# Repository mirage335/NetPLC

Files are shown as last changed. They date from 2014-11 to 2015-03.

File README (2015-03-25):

Copyright (C) 2014 mirage335
See the end of the file for license conditions.
See license.txt for NetPLC license conditions.

Advanced multi-peripherial low-power Networked Programmable Logic Controller (NetPLC) core platform.

__Usage__
NetPLC is intended as a robust control system with networking support. Expected use cases include door locks, occupancy sensors, temperature sensors, efficiency smart meters, thermostats, wind farms, 3D printers, etc.

'General Purpose' and 'Precision Analog' RJ45 jacks may be used to attach attach additional microcontrollers, cameras, thermistors, pressure sensors, current/voltage transformers, power transistors, relays, etc.

In harsh environments (eg. mains voltage, flourescent lighting), surge suppression may be maximized by use of genuine S/FTP cable as well as maintaining AVR pins in output LOW state when possible. Watchdog is also recommended.

Ethernet jack is provided for full 10BaseT support. WiFi support is also provided via RN171 module. Headers are provided for preassembled pin-compatible Ethernet and WiFi peripherials.

For maximum network reliability, consider configuring both Ethernet and WiFi for automatic connection, as mutual fallbacks.

__Design__
Efforts have been made to provide surge suppression, especially for the RJ45 peripherials. However, sustained faults below the spark-gap voltage threshold and above the AVR protection diode current limits will cause damage. As noted above, extra precautions should be taken against such mid-level interference in harsh environments.

Layout is important. Digital circuits create a multitude of full-swing square waves at radio frequency. Stray coupling of these transients into analog circuits can introduce both low and high frequency noise through a variety of mechanisms.

USA companies provide all parts in these schematics.

__Extras__
Any isolated USB charger can be used as a power source. For example, consider http://www.amazon.com/Samsung-Power-Adapter-Detachable-Micro/dp/B0089VO7FQ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 .

Typical 1/16" PCBs will not be thick enough to ensure reliable USB port contact. Consider adding a few layers of electrical or duct tape to the back side.

__Safety__
Typical TCP/IP and wireless networks are vastly more complex, less reliable, more difficult to surge-protect, and less secure than the onboard MCU. Firmware should be written not to depend on network connectivity for control loops where reliability counts. Unrestricted public internet services (eg. HTTP) should be directed through a full server, supporting load and security requirements if possible.

While the MCU alone is unlikely to fail within decades, it should not be relied upon for safety-of-life control systems. Generally, a microcontroller is less dependable than redundant, specialized, discrete logic. Indirect use of NetPLC (eg. monitoring outcomes, contributing information, etc) in such systems must be carefully considered by a competent engineer.

_FutureWork_
*) SD Card slot should be added to enhance database and logging capacity.
*) RN171 should be moved to software serial port, completely freeing the hardware UART for external peripherials.
*) Modbus and DNP3 support have been suggested by George Walker. Related open-source libraries seem to already exist, and may be worth testing.

__Copyright__
This file is part of NetPLC.

NetPLC is free software: you can redistribute it and/or modify
it under the terms of the GNU General Public License as published by
the Free Software Foundation, either version 3 of the License, or
(at your option) any later version.

NetPLC is distributed in the hope that it will be useful,
but WITHOUT ANY WARRANTY; without even the implied warranty of
MERCHANTABILITY or FITNESS FOR A PARTICULAR PURPOSE.  See the
GNU General Public License for more details.

You should have received a copy of the GNU General Public License
along with NetPLC.  If not, see <http://www.gnu.org/licenses/>.

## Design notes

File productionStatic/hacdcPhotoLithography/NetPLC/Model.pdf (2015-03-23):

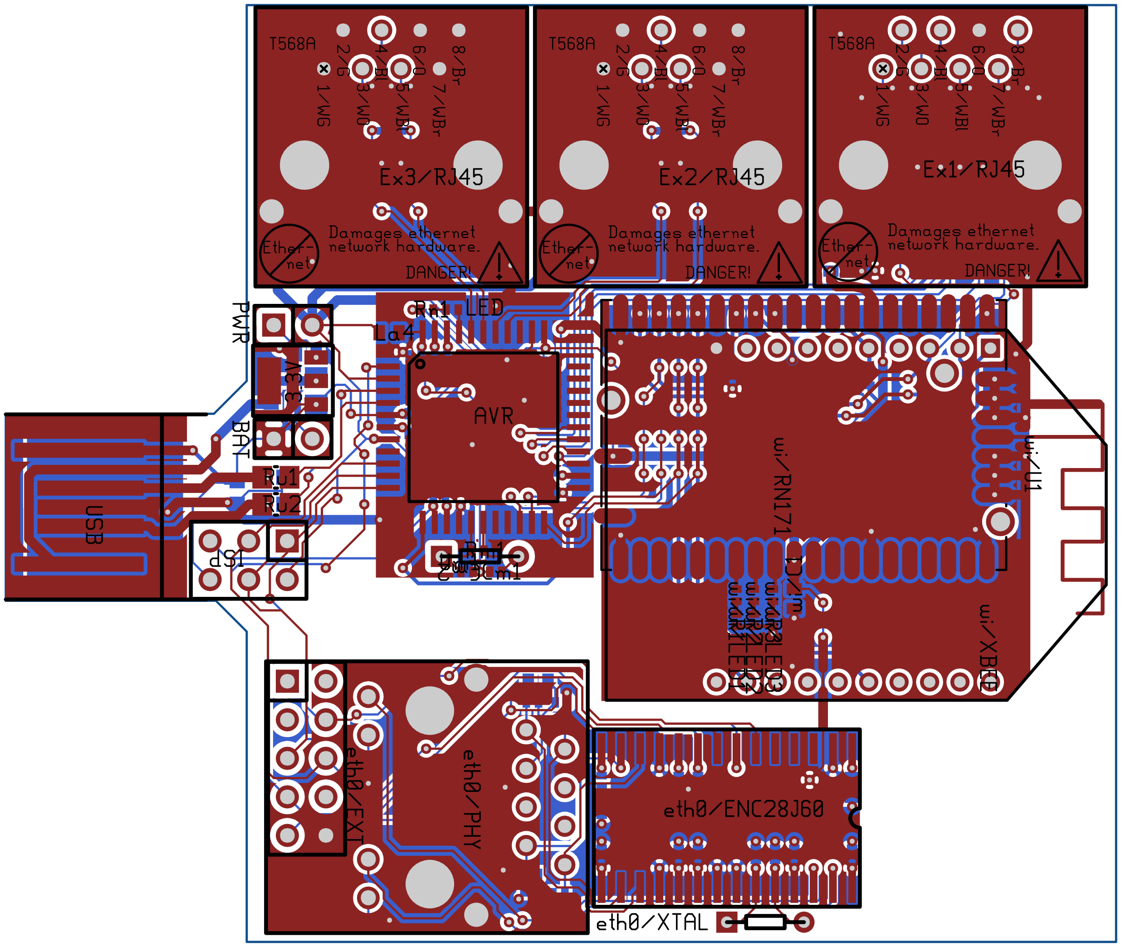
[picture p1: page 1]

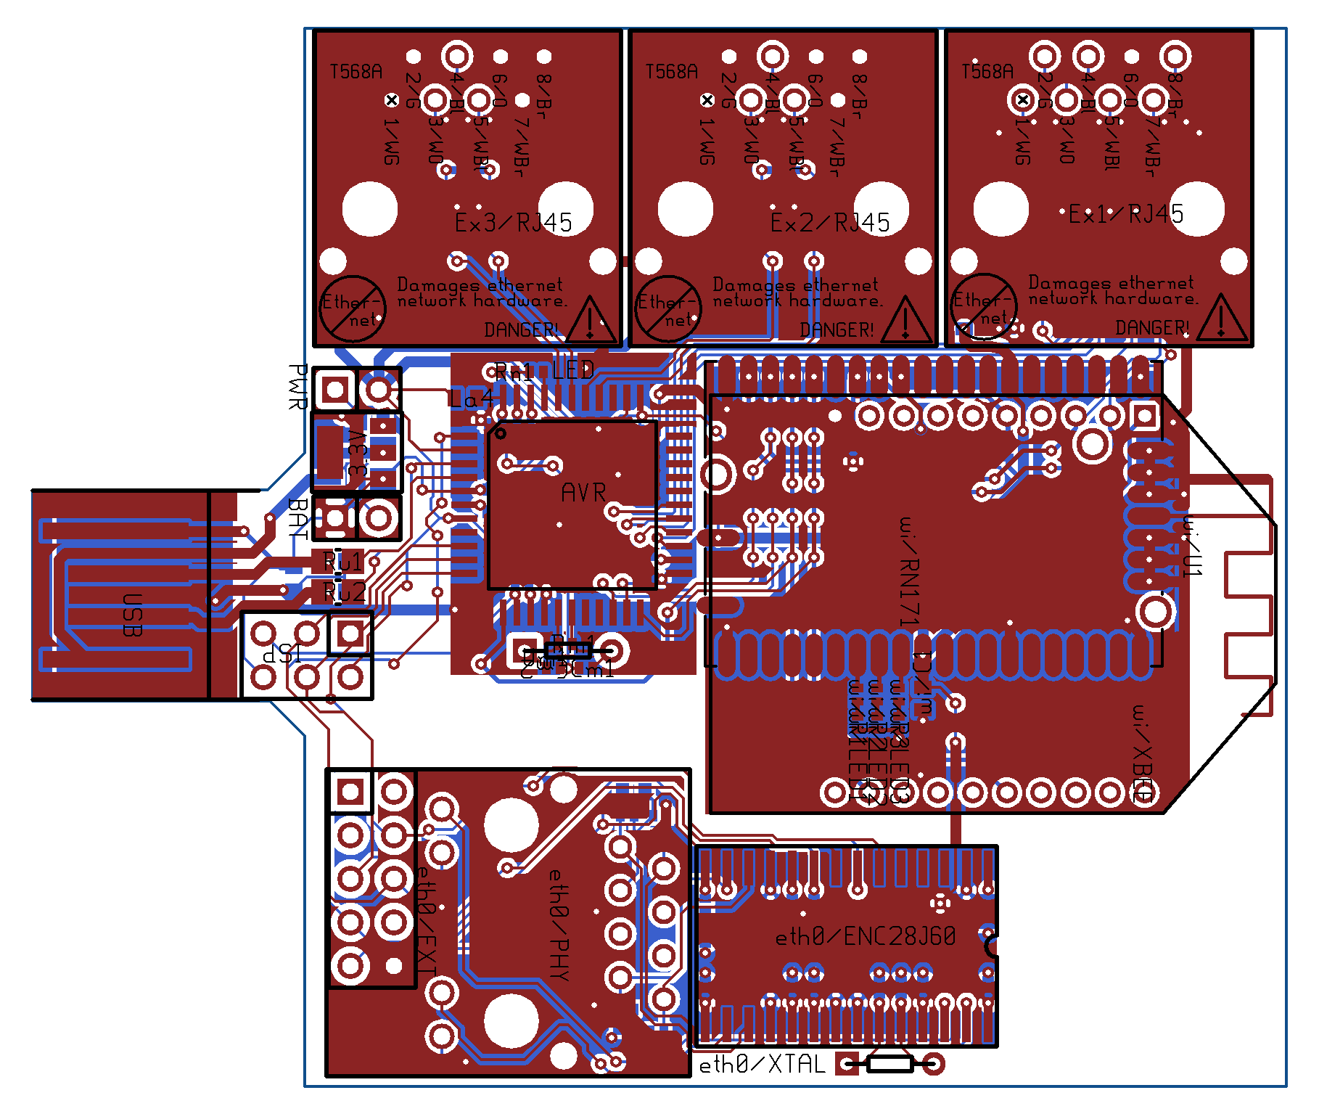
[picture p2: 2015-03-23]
productionStatic/cad/NetPLC/Render.png

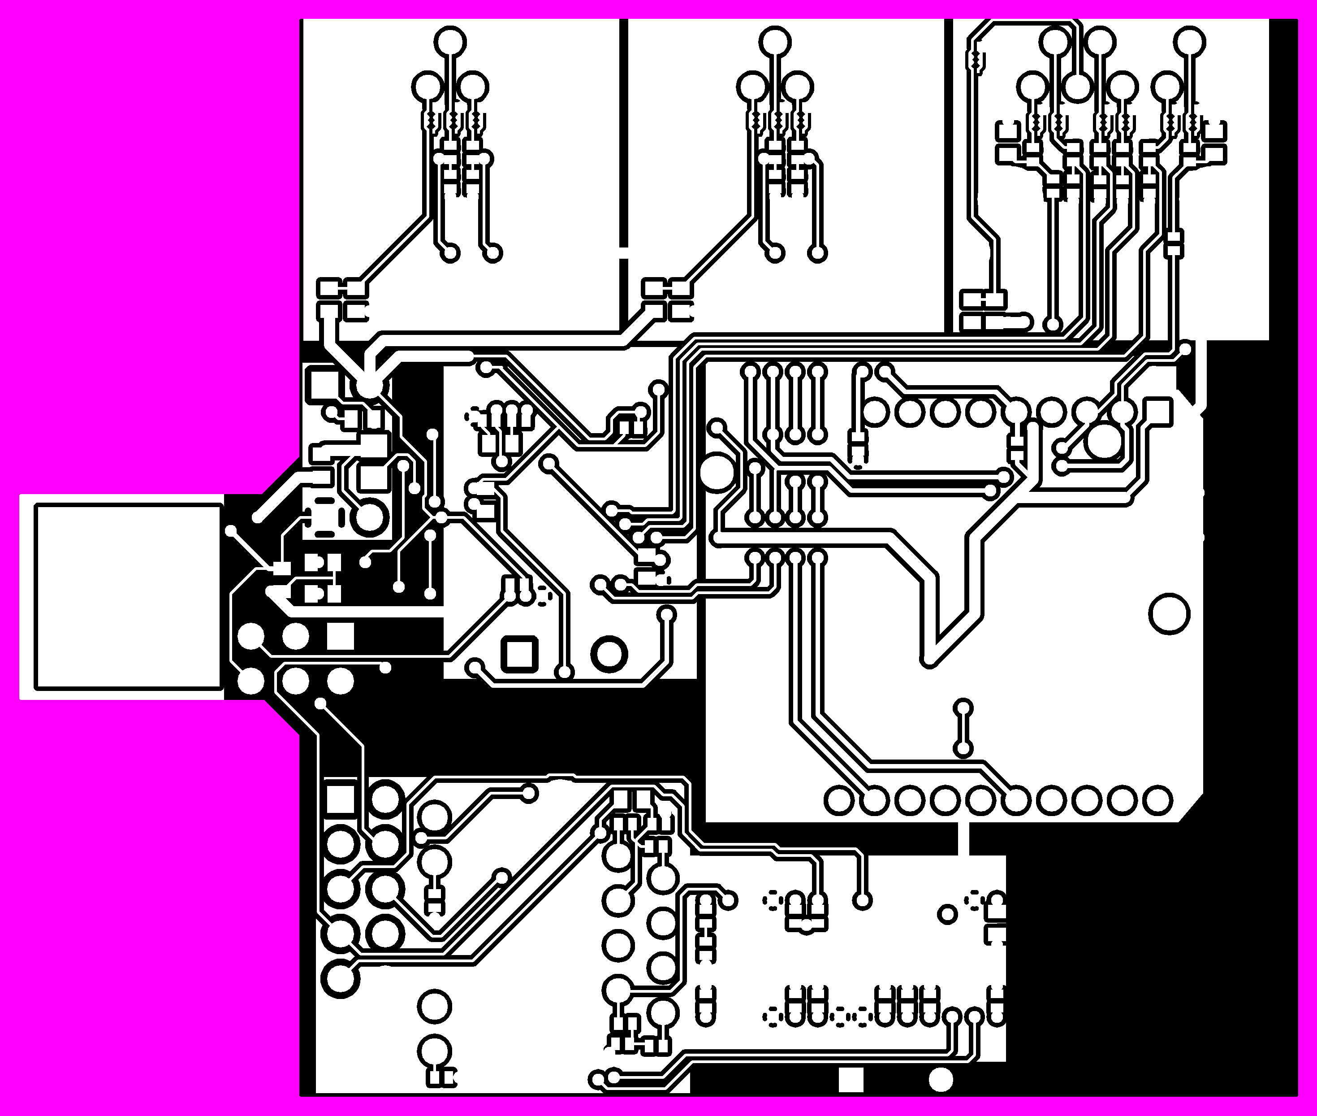
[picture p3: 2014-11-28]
productionStatic/hacdcCNC/NetPLC/outp4_masked.png

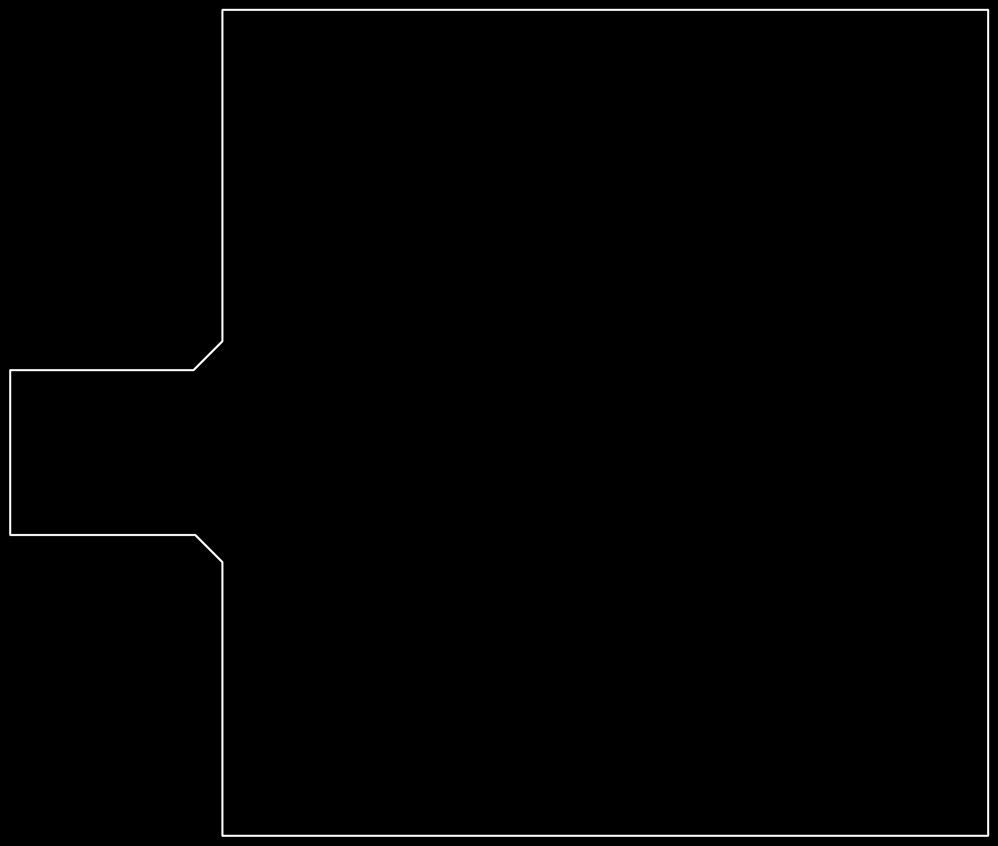
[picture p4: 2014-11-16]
productionStatic/hacdcCNC/NetPLC/outp2_original_outline.png

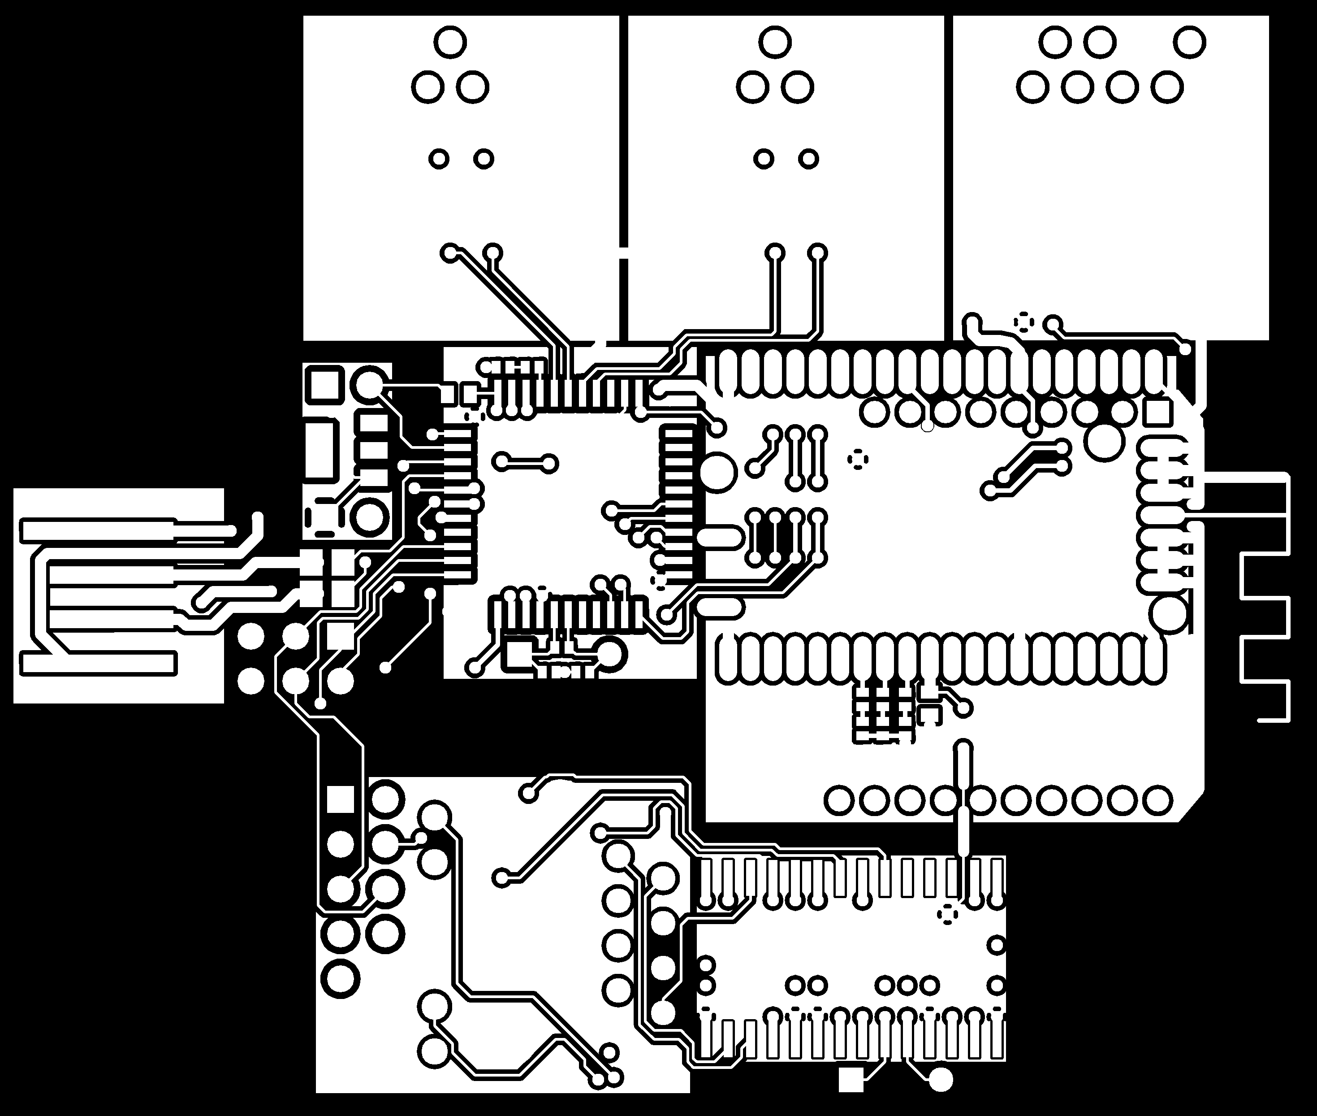
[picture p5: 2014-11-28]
productionStatic/hacdcCNC/NetPLC/outp1_original_front.png

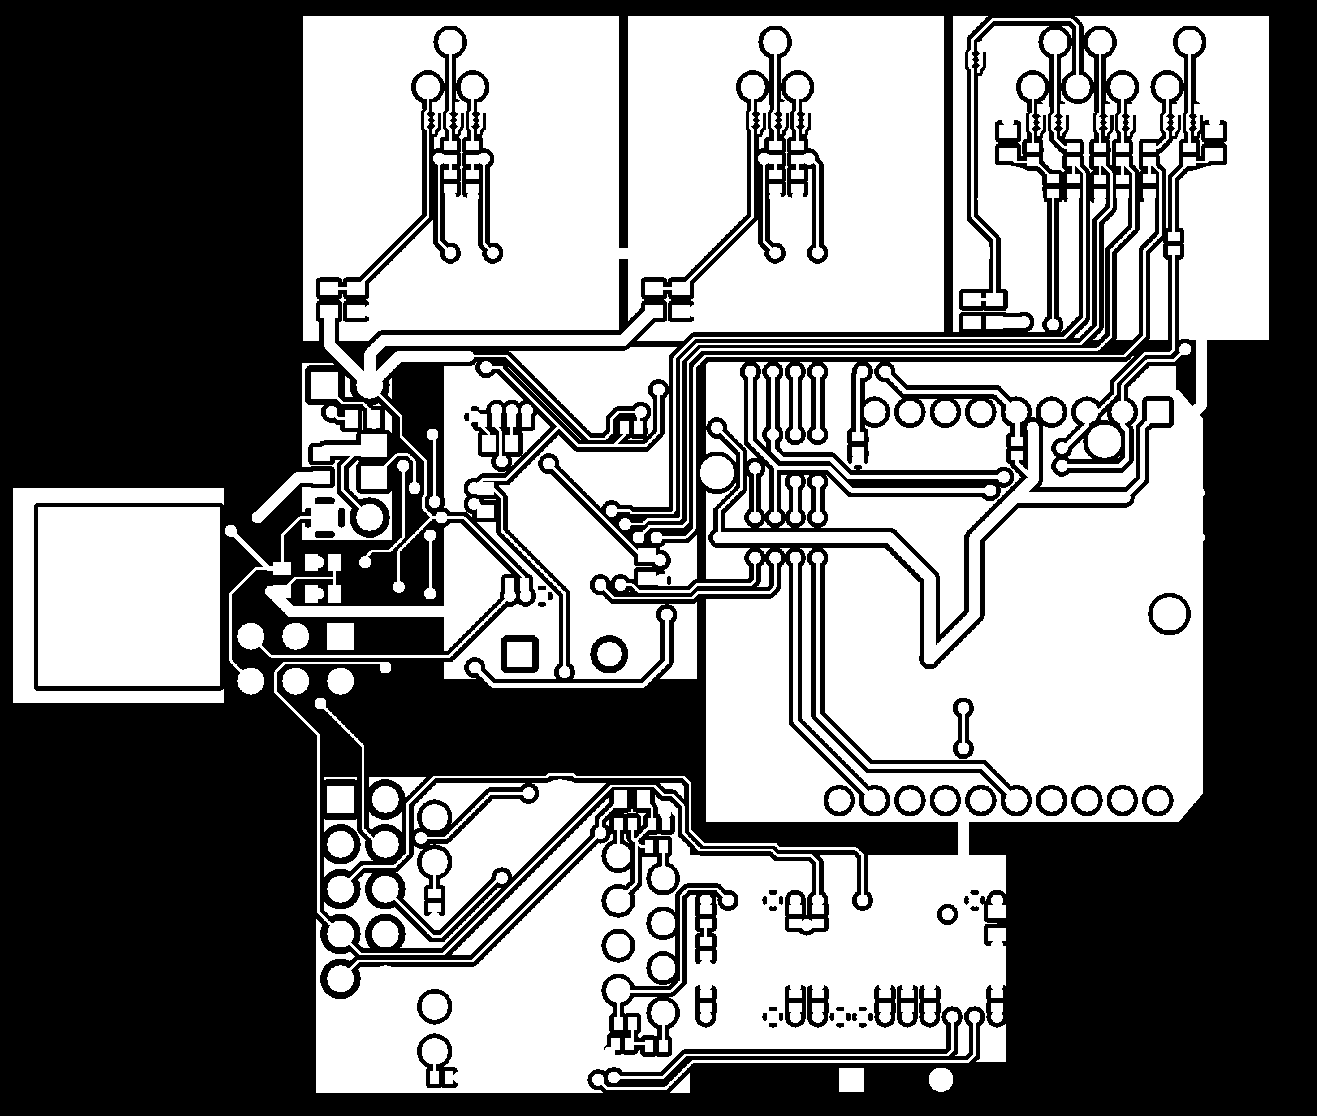
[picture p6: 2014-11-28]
productionStatic/hacdcCNC/NetPLC/outp0_original_back.png

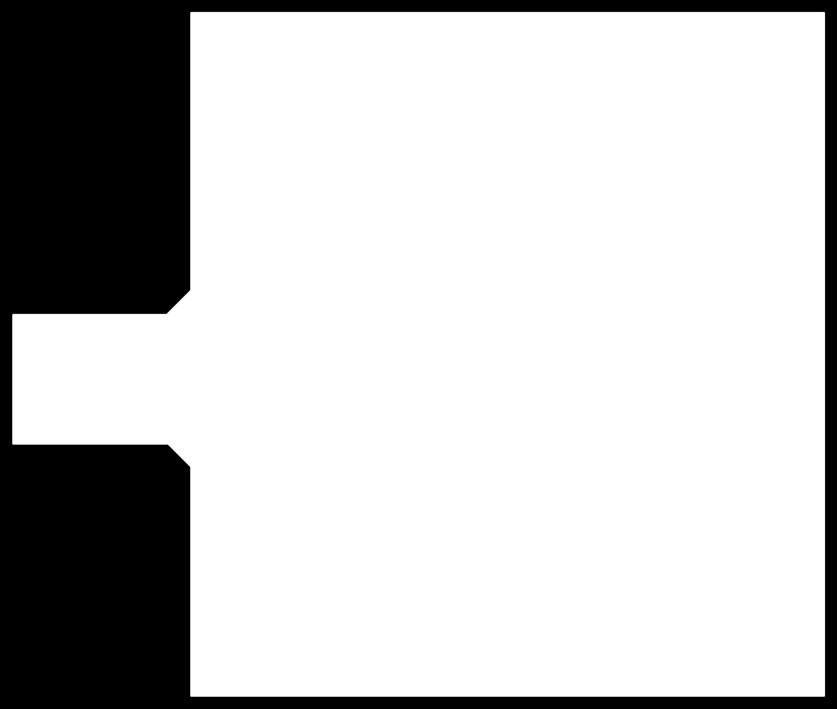
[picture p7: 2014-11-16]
productionStatic/hacdcCNC/NetPLC/outp3_outline_filled.png

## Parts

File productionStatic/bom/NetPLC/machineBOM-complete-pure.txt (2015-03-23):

AVR:ATMEGA32U4-AU:-:TQFP44_10:$6.04 MOUSER 556-ATMEGA32U4-AU:1
Rm1:RESISTOR:1M:0402:$0.14 MOUSER 594-MCS04020C1004FE0:1
Um1:CRYSTAL:16MHz:ACY200:$0.39 MOUSER ABL-16.000MHZ-B2:1
Ru1,Ru2:RESISTOR:22:0805:$0.52 MOUSER 71-TNPW080522R1BEEA:2
USB:CONNECTOR_5:-:USB_TypeA_PCB:$0.00 PCB-INTEGRAL Trace based connector.:1
3.3V:Microchip MCP170x regulator TO92:-:SOT89:$0.60 MOUSER 579-MCP1703AT3302EMB:1
ISP:CONNECTOR_6:-:HEADER6_2:$0.25 MOUSER 649-77313-818-06LF:1
BAT,PWR:CONNECTOR_2:-:HEADER2_1:-:2
eth0/ENC28J60:ENC28J60:-:SO28:$3.40 MOUSER 579-ENC28J60-I/SO:1
eth0/PHY:CONNECTOR_12:-:MAGJACK:$1.95 SparkFun PRT-08534:1
eth0/EXT:CONNECTOR_10:-:HEADER10_1:-:1
eth0/XTAL:CRYSTAL:25MHz:ACY200:$0.39 MOUSER 815-ABL-25-B2F:1
Cm1,Cm2,eth0/Ce4,eth0/Ce5:CAPACITOR:22p:0402:$0.10 MOUSER 80-C0402C220J5G:4
Ri1,eth0/Re2:RESISTOR:10k:0402:$0.13 MOUSER 71-TNPW040210K0DETD:2
Ex1/MOV1,Ex1/MOV2,Uu1,Uu2:ESD_Suppressor:-:0603:$0.13 MOUSER 652-CG0603MLC-05E:4
Ex1/L1,Ex2/L1,Ex3/L1,La1,La3,La4,Lp1,eth0/Lp1:INDUCTOR:4.7uH:0603:$0.12 MOUSER 70-ILSB0603ER4R7K:8
Ex1/R2,Ex1/R3,Ex1/R4,Ex1/R5,Ex1/R7,Ex1/R8,Ex2/R1,Ex2/R2,Ex3/R1,Ex3/R2,eth0/Rp1,eth0/Rp2,eth0/Rp3,eth0/Rp4:RESISTOR:50:0402:$0.08 MOUSER 71-CRCW0402-49.9-E3:14
Ca2,Ca3,Cm3,Ex1/C2,Ex1/C3,Ex1/C4,Ex1/C5,Ex2/C1,Ex2/C2,Ex3/C1,Ex3/C2,eth0/Ce2,eth0/Ce3,eth0/Ce6,eth0/Ce7,eth0/Ce8,eth0/Cp1,eth0/Cp2:CAPACITOR:0.1u:0402:$0.10 MOUSER 80-C0402C104K8R:18
Ex1/RJ45,Ex2/RJ45,Ex3/RJ45:CONNECTOR_9:-:538-95540-2881:$1.75 MOUSER 538-95540-2881:3
Ex1/SPRK1,Ex1/SPRK2,Ex1/SPRK3,Ex1/SPRK4,Ex1/SPRK5,Ex1/SPRK6,Ex1/SPRK7,Ex2/SPRK1,Ex2/SPRK2,Ex2/SPRK3,Ex3/SPRK1,Ex3/SPRK2,Ex3/SPRK3:GLOW_LAMP:~2kV:SparkGap:-:13
wi/RN171:RN171:12dBm:RN171:$31.50 MOUSER 765-RN-171:1
wi/U1:traceAnt:50Ohm@2.4GHz:50Ohm2point4GHzTraceAntenna:-:1
Ca4,Cp2,Cu1,Ex1/C1,Ex2/C3,Ex3/C3,eth0/Ce1,wi/C1:CAPACITOR:4.7u:0603:$0.13 MOUSER 80-C0603C475K9P:8
eth0/Re1,wi/R4,wi/R5:RESISTOR:100k:0402:$0.14 MOUSER 594-MCS04020C1003FE0:3
Ex1/R1,Ex1/R6,Rn1,eth0/Re3,eth0/Re4,eth0/Rp5,eth0/Rp6,wi/R1,wi/R2,wi/R3:RESISTOR:1k:0402:$0.14 MOUSER 594-MCS0402MC1001FE0:10
LED,wi/LED1,wi/LED2,wi/LED3:LED:-:0402:$0.09 MOUSER 78-VLMG1500-GS08:4
wi/XBEE:Xbee:-:XbeePro:$34.95 SparkFun WRL-10822:1
Cp1:CAPACITOR:4.7u:0805:$0.06 MOUSER 77-VJ0805V475ZXQTBC:1

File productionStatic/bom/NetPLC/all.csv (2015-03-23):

(AVR) | ATMEGA32U4-AU | - | TQFP44_10 | $6.04 MOUSER 556-ATMEGA32U4-AU | 1 | $6.04 | 556-ATMEGA32U4-AU | 1
(Rm1) | RESISTOR | 1M | 0402 | $0.14 MOUSER 594-MCS04020C1004FE0 | 1 | $0.14 | 594-MCS04020C1004FE0 | 1
(Um1) | CRYSTAL | 16MHz | ACY200 | $0.39 MOUSER ABL-16.000MHZ-B2 | 1 | $0.39 | ABL-16.000MHZ-B2 | 1
(Ru1|Ru2) | RESISTOR | 22 | 0805 | $0.52 MOUSER 71-TNPW080522R1BEEA | 2 | $0.52 | 71-TNPW080522R1BEEA | 2
(USB) | CONNECTOR_5 | - | USB_TypeA_PCB | $0.00 PCB-INTEGRAL Trace based connector. | 1 | $0.00 |  | 1
(3.3V) | Microchip MCP170x regulator TO92 | - | SOT89 | $0.60 MOUSER 579-MCP1703AT3302EMB | 1 | $0.60 | 579-MCP1703AT3302EMB | 1
(ISP) | CONNECTOR_6 | - | HEADER6_2 | $0.25 MOUSER 649-77313-818-06LF | 1 | $0.25 | 649-77313-818-06LF | 1
(BAT|PWR) | CONNECTOR_2 | - | HEADER2_1 | - | 2 | - |  | 2
(eth0/ENC28J60) | ENC28J60 | - | SO28 | $3.40 MOUSER 579-ENC28J60-I/SO | 1 | $3.40 | 579-ENC28J60-I/SO | 1
(eth0/PHY) | CONNECTOR_12 | - | MAGJACK | $1.95 SparkFun PRT-08534 | 1 | $1.95 |  | 1
(eth0/EXT) | CONNECTOR_10 | - | HEADER10_1 | - | 1 | - |  | 1
(eth0/XTAL) | CRYSTAL | 25MHz | ACY200 | $0.39 MOUSER 815-ABL-25-B2F | 1 | $0.39 | 815-ABL-25-B2F | 1
(Cm1|Cm2|eth0/Ce4|eth0/Ce5) | CAPACITOR | 22p | 0402 | $0.10 MOUSER 80-C0402C220J5G | 4 | $0.10 | 80-C0402C220J5G | 4
(Ri1|eth0/Re2) | RESISTOR | 10k | 0402 | $0.13 MOUSER 71-TNPW040210K0DETD | 2 | $0.13 | 71-TNPW040210K0DETD | 2
(Ex1/MOV1|Ex1/MOV2|Uu1|Uu2) | ESD_Suppressor | - | 0603 | $0.13 MOUSER 652-CG0603MLC-05E | 4 | $0.13 | 652-CG0603MLC-05E | 4
(Ex1/L1|Ex2/L1|Ex3/L1|La1|La3|La4|Lp1|eth0/Lp1) | INDUCTOR | 4.7uH | 0603 | $0.12 MOUSER 70-ILSB0603ER4R7K | 8 | $0.12 | 70-ILSB0603ER4R7K | 8
(Ex1/R2|Ex1/R3|Ex1/R4|Ex1/R5|Ex1/R7|Ex1/R8|Ex2/R1|Ex2/R2|Ex3/R1|Ex3/R2|eth0/Rp1|eth0/Rp2|eth0/Rp3|eth0/Rp4) | RESISTOR | 50 | 0402 | $0.08 MOUSER 71-CRCW0402-49.9-E3 | 14 | $0.08 | 71-CRCW0402-49.9-E3 | 14
(Ca2|Ca3|Cm3|Ex1/C2|Ex1/C3|Ex1/C4|Ex1/C5|Ex2/C1|Ex2/C2|Ex3/C1|Ex3/C2|eth0/Ce2|eth0/Ce3|eth0/Ce6|eth0/Ce7|eth0/Ce8|eth0/Cp1|eth0/Cp2) | CAPACITOR | 0.1u | 0402 | $0.10 MOUSER 80-C0402C104K8R | 18 | $0.10 | 80-C0402C104K8R | 18
(Ex1/RJ45|Ex2/RJ45|Ex3/RJ45) | CONNECTOR_9 | - | 538-95540-2881 | $1.75 MOUSER 538-95540-2881 | 3 | $1.75 | 538-95540-2881 | 3
(Ex1/SPRK1|Ex1/SPRK2|Ex1/SPRK3|Ex1/SPRK4|Ex1/SPRK5|Ex1/SPRK6|Ex1/SPRK7|Ex2/SPRK1|Ex2/SPRK2|Ex2/SPRK3|Ex3/SPRK1|Ex3/SPRK2|Ex3/SPRK3) | GLOW_LAMP | ~2kV | SparkGap | - | 13 | - |  | 13
(wi/RN171) | RN171 | 12dBm | RN171 | $31.50 MOUSER 765-RN-171 | 1 | $31.50 | 765-RN-171 | 1
(wi/U1) | traceAnt | 50Ohm@2.4GHz | 50Ohm2point4GHzTraceAntenna | - | 1 | - |  | 1
(Ca4|Cp2|Cu1|Ex1/C1|Ex2/C3|Ex3/C3|eth0/Ce1|wi/C1) | CAPACITOR | 4.7u | 0603 | $0.13 MOUSER 80-C0603C475K9P | 8 | $0.13 | 80-C0603C475K9P | 8
(eth0/Re1|wi/R4|wi/R5) | RESISTOR | 100k | 0402 | $0.14 MOUSER 594-MCS04020C1003FE0 | 3 | $0.14 | 594-MCS04020C1003FE0 | 3
(Ex1/R1|Ex1/R6|Rn1|eth0/Re3|eth0/Re4|eth0/Rp5|eth0/Rp6|wi/R1|wi/R2|wi/R3) | RESISTOR | 1k | 0402 | $0.14 MOUSER 594-MCS0402MC1001FE0 | 10 | $0.14 | 594-MCS0402MC1001FE0 | 10
(LED|wi/LED1|wi/LED2|wi/LED3) | LED | - | 0402 | $0.09 MOUSER 78-VLMG1500-GS08 | 4 | $0.09 | 78-VLMG1500-GS08 | 4
(wi/XBEE) | Xbee | - | XbeePro | $34.95 SparkFun WRL-10822 | 1 | $34.95 |  | 1
(Cp1) | CAPACITOR | 4.7u | 0805 | $0.06 MOUSER 77-VJ0805V475ZXQTBC | 1 | $0.06 | 77-VJ0805V475ZXQTBC | 1

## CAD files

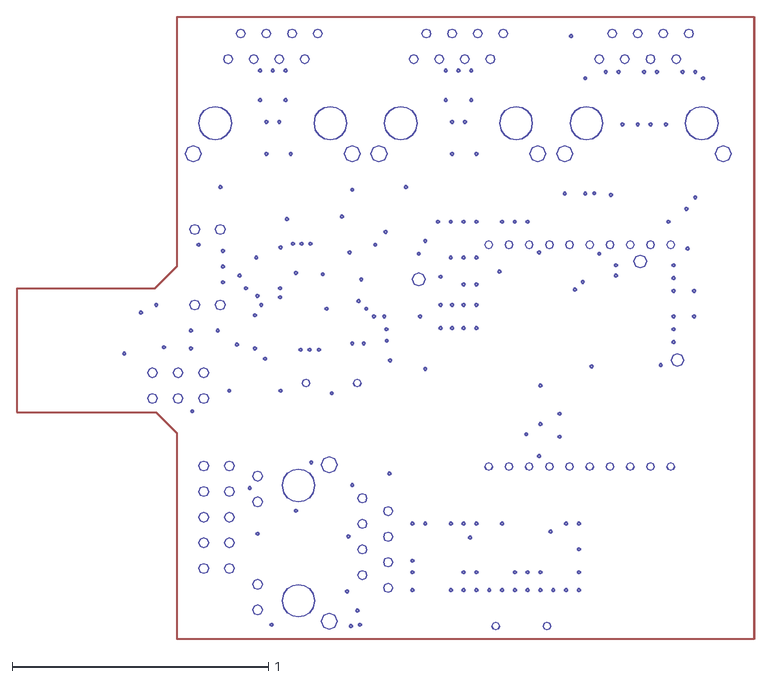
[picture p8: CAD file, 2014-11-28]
productionStatic/cad/NetPLC/combined.dxf
2.89 x 2.44

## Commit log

2014-11-16 Technically complete.
    [NetPLC.sch]
2014-11-16 Improved input capacitor voltage tolerance, TVS diode array symbol.
    [NetPLC.sch]
2014-11-16 Stronger transient voltage protection in progress.
    [RJ45-GeneralPurpose-sys.sch, RJ45-PrecisionAnalog-sys.sch]
2014-11-16 Subystem upgrade complete.
    [RJ45-GeneralPurpose-sys.sch]
2014-11-16 Improved surge protection.
    [NetPLC.sch, RJ45-GeneralPurpose-sys.sch, RJ45-PrecisionAnalog-sys.sch]
2014-11-16 New production assets.
    [NetPLC.bottom.gbr, NetPLC.bottommask.gbr, NetPLC.bottompaste.gbr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]
2014-11-16 Safety and expected use case information.
    [NetPLC.bottom.gbr, NetPLC.bottommask.gbr, NetPLC.bottompaste.gbr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]
2014-11-27 Incorrect wiring removed.
    [NetPLC.sch]
2014-11-27 UART bugfix.
    [NetPLC.sch]
2014-11-28 Production assets.
    [NetPLC.bottom.gbr, NetPLC.bottommask.gbr, NetPLC.bottompaste.gbr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]
